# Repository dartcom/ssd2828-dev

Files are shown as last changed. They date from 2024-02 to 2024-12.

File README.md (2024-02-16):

# SSD2828-DEV
A collection of boards to test the SSD2828 RGB to MIPI Converter with the LH154Q01 panel by AUO and the VS035ZSM by BOE. The boards are meant to be ordered as a single unit and then be separated using a box cutter ( the dust generated by cutting cutting FR4 is carcenogenic PLEASE be carefull! ).

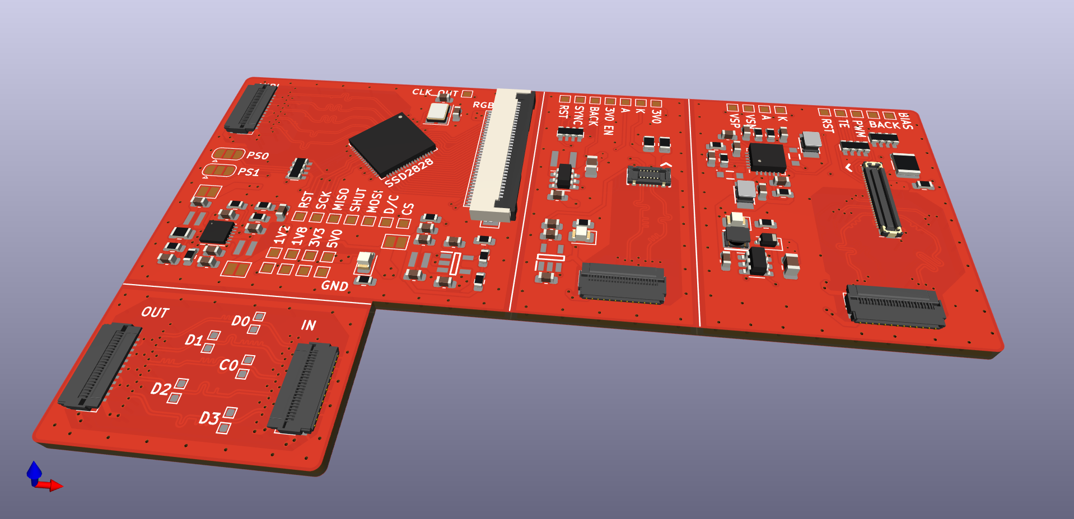
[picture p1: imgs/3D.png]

<br></br>

# The pcb
The pcb is designed using the JLC04161H-7628 stackup by JLCPCB.  The MIPI DSI protool requires controlled impedance traces to function properly (100Ω differental, 50Ω single ended), depending on the provided pcb stackup different trace widths and spacings need to be selected. Additionally the signals must be kept away from noise sources such as inductors and other signals. When switching layers with MIPI signals, GND vias need to be placed near the signal vias.

# LH154Q01 panel
The LH154Q01 panel has been tested and is working correctly.

The panel does not support packed pixel stream packets, the only way to send pixel data to the display, is through DCS commands. in this demo, a STM32f401 is sending the the write_memory_continue(0x3C) DCS command containing pixel data, through SPI to the SSD2828. 


<br></br>

# VS035ZSM panel
The VS035ZSM panel has been tested and is working correctly.

The panel gets initialized on MIPI LP mode and the video is transmitted MIPI HS mode @912Mbps per lane. The ssd2828 is generating the test video signal called BIST. The panel has 8-bit color depth, reaning each pixel requires 24bits. The resolution of the panel is 1400x1600, including the porch values the total resoution is 1470 x 167. To operate at 60fps, 1470 x 1670 x 24 x 60 = 3.53Gbps are required resulting at 883Mbps per lane. The panel also suppors VESA DSC making 90fps operation possible. Unfortunately the SSD2828 does not include a DSC encoder. 

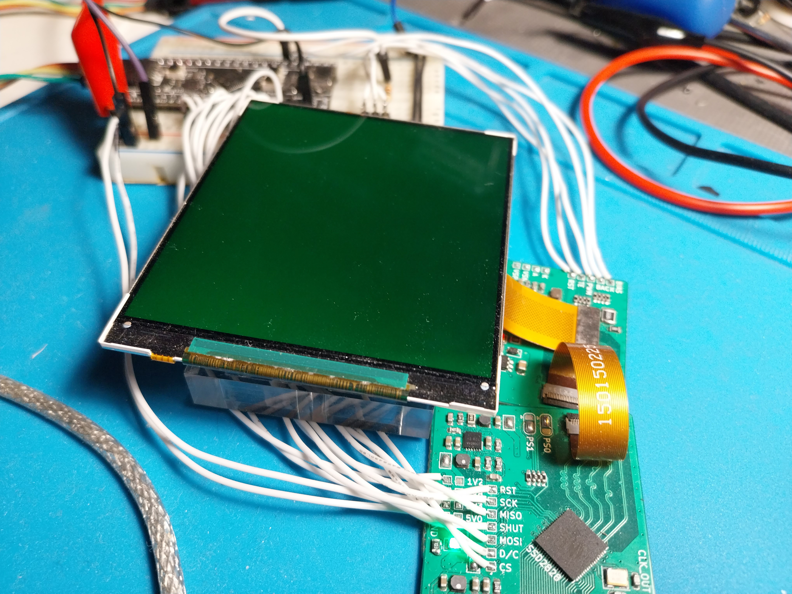
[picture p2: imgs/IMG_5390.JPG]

<br></br>

# Resources
### PCB
- [jlcpcb capabilities](https://jlcpcb.com/capabilities/pcb-capabilities).
- [jlcpcb impedance calculator](https://jlcpcb.com/pcb-impedance-calculator).
- [Jacinto 7 High-Speed Interface Layout Guidelines](https://www.ti.com/lit/an/spracp4/spracp4.pdf?ts=1708080453311&ref_url=https%253A%252F%252Fwww.google.com%252F).
- [MIPI DSI guidelines]( https://electronics.stackexchange.com/questions/610671/mipi-dsi-differential-pair-layout-guidance).
- [High-Speed PCB Design Tips - Phil's Lab](https://www.youtube.com/watch?v=VRJI0X-6yTg).
- [Differential Pairs - PCB Design Basics - Phil's Lab](https://www.youtube.com/watch?v=xwrdvhm4vgw).

### SSD2828
- [SSD2828 RGB转MIPI转换板制作（1)](https://blog.csdn.net/weixin_37214729/article/details/123339267).
- [SSD2828 RGB转MIPI转换板制作（2)](https://blog.csdn.net/weixin_37214729/article/details/127710648).
- [SSD2828调试记录](https://blog.csdn.net/luoqindong/article/details/39349333).
- [project-display](https://github.com/jlywxy/project-display).
- [Index of /lcd/ssd2828/](http://www.internetsomething.com/lcd/ssd2828/).

### LH154Q01
- [Driving IPOD Nano 6 MIPI LCD Using FPGA](https://www.circuitvalley.com/2020/01spi-mipi-bridge-fpga-verilog-hdl-ipod-nano-nano-lcd-iphone-mipi-lcd.html).
- [SSD2805 w/ LH154Q01](https://github.com/techtoys/SSD2805/blob/master/Microchip/Graphics/Drivers/SSD2805.c).
### VS035ZSM
- [Project North Star](https://github.com/leapmotion/ProjectNorthStar).

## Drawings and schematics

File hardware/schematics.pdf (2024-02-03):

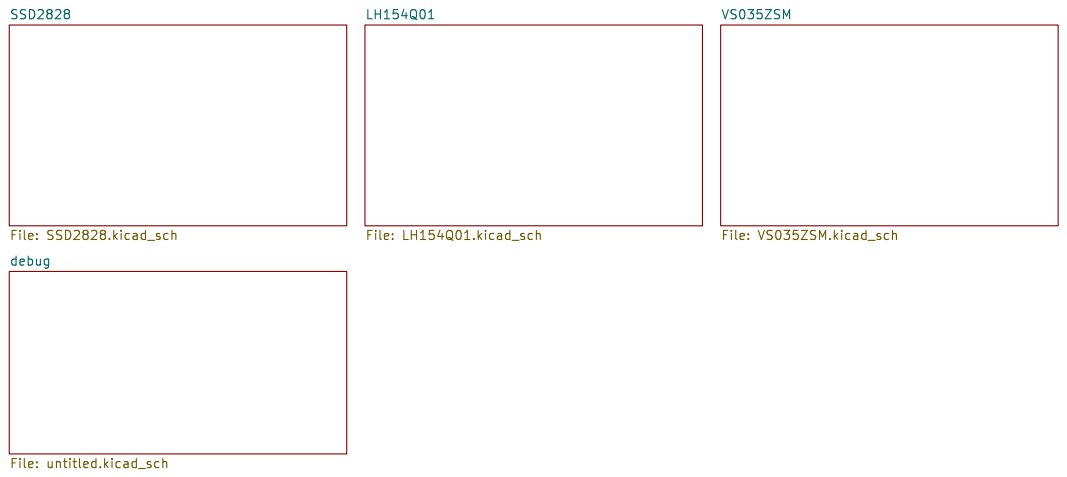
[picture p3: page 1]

debug File: untitled.kicad_sch SSD2828 File: SSD2828.kicad_sch

Id: 1/5 Title: File: ssd2828_board.kicad_sch Sheet: /

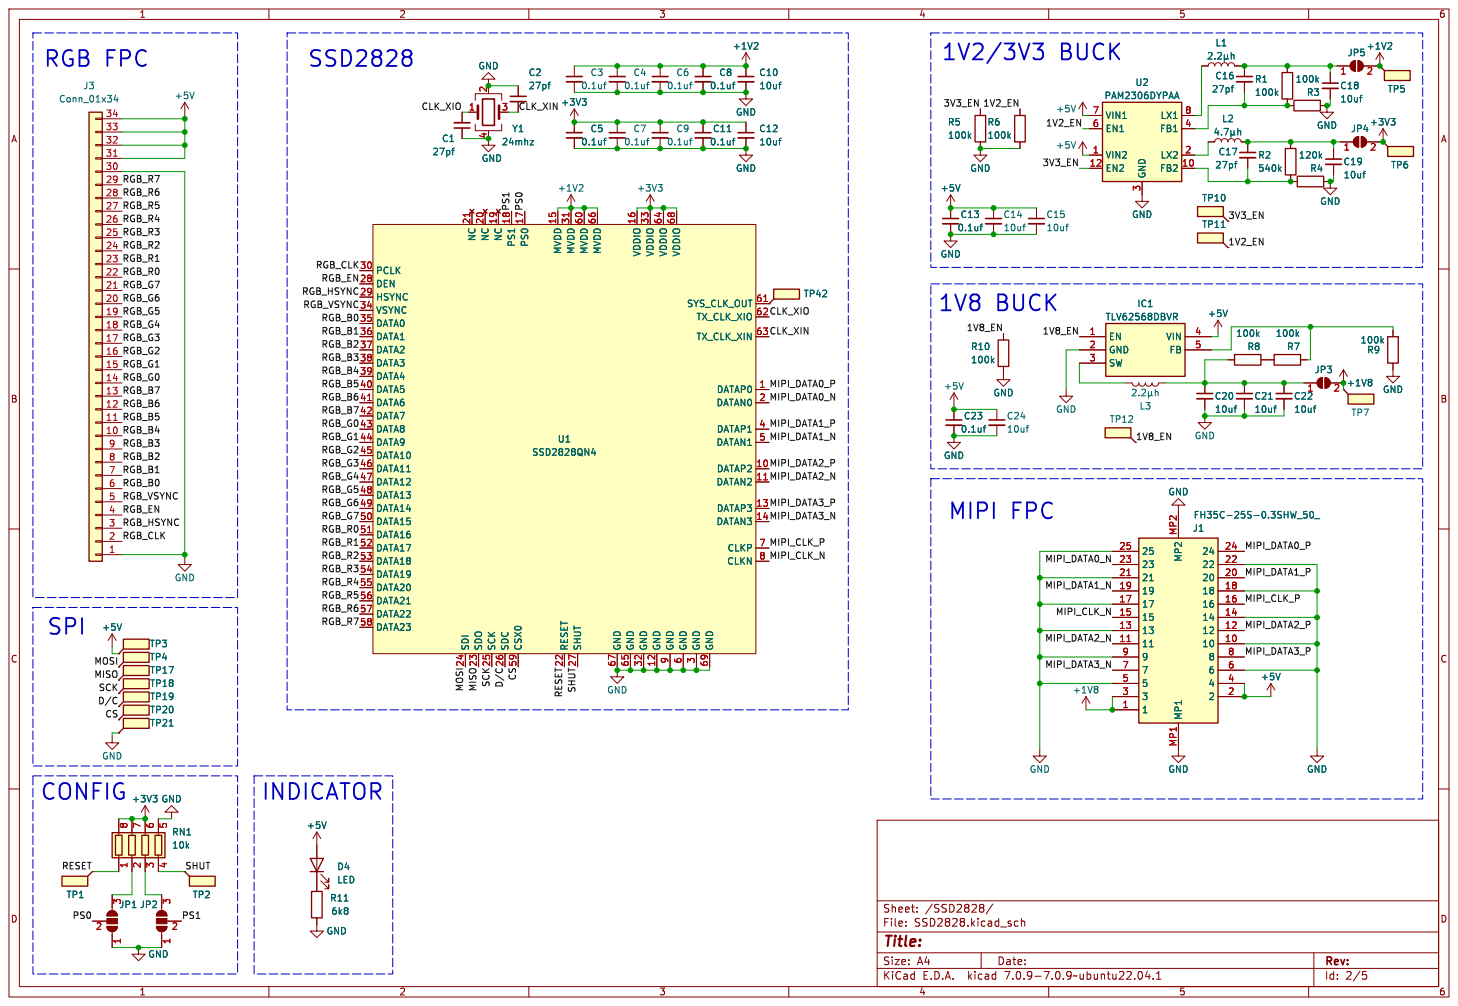
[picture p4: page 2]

3 PCLK 30 MVDD 31 GND 32 VDDIO 33 VSYNC 34 DATA0 35 DATA1 36 DATA2 37 DATA3 38 DATA4 39 DATAP1 4 DATA5 40 DATA6 41 DATA7 42 DATA8 43 DATA9 44 DATA10 45 DATA11 46 DATA12 47 DATA13 48 DATA14 49 DATAN1 5 DATA15 50 DATA16 51 DATA17 52 DATA18 53 DATA19 54 DATA20 55 DATA21 56 DATA22 57 DATA23 58 CSX0 59 GND

6 MVDD 60 SYS_CLK_OUT 61 TX_CLK_XIO 62 TX_CLK_XIN 63 VDDIO 64 GND 65 MVDD 66 GND 67 VDDIO 68 GND 69 CLKP 7 CLKN 8 GND

Id: 2/5 Title: File: SSD2828.kicad_sch Sheet: /SSD2828/

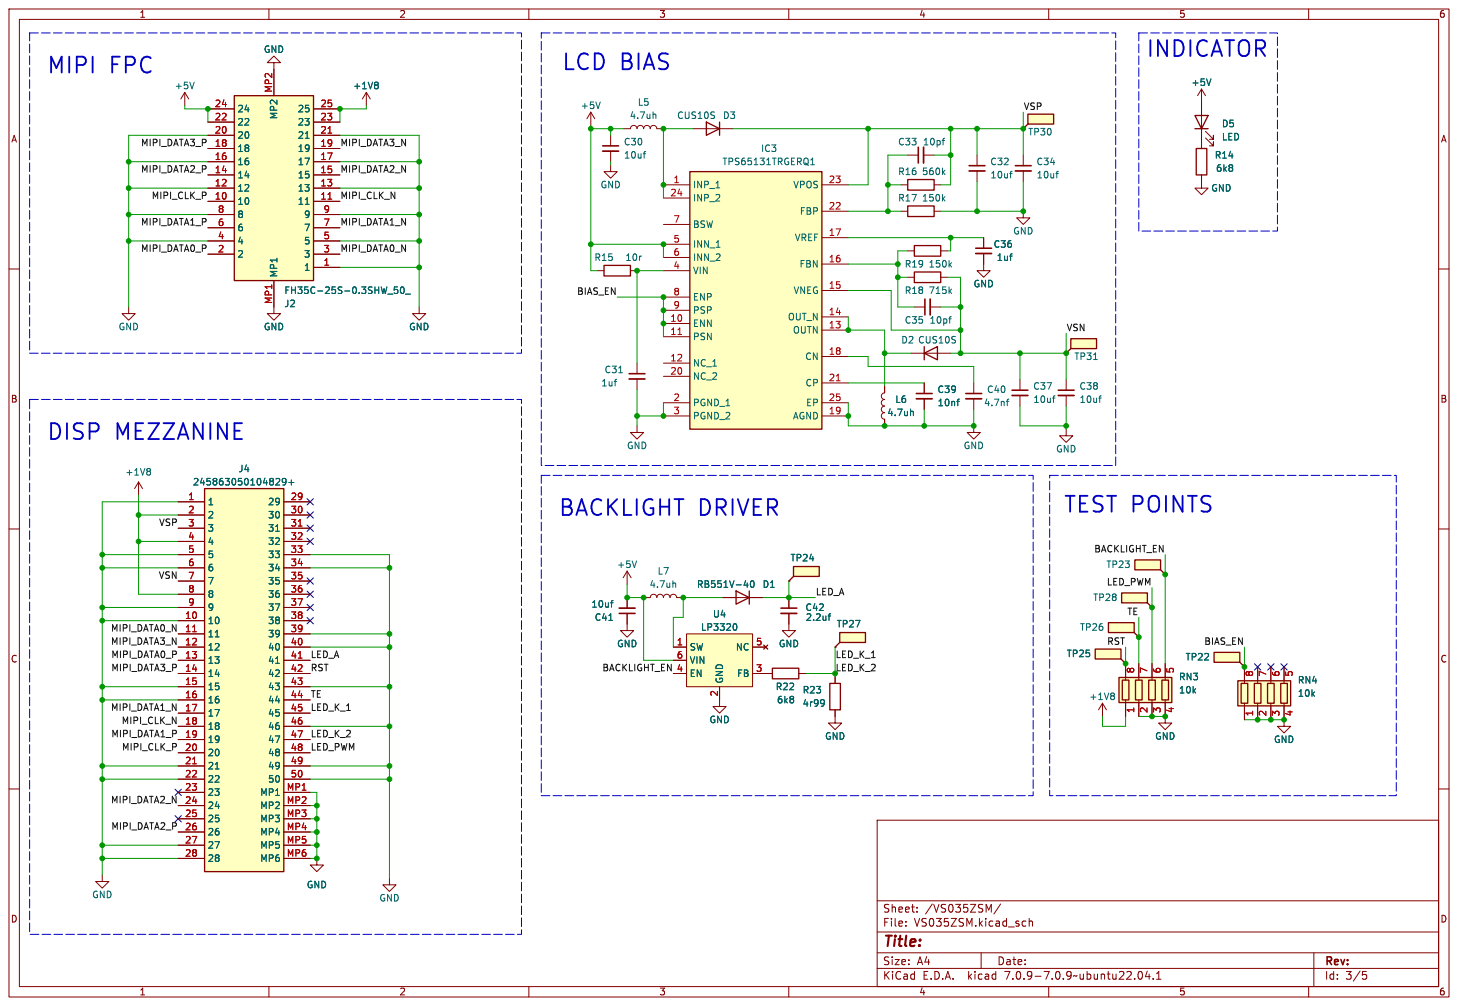
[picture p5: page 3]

2 FB 3 EN 4 NC 5 VIN 6 U4
2.2uf GND

2 FB 3 EN 4 NC 5 VIN 6 TP27 GND

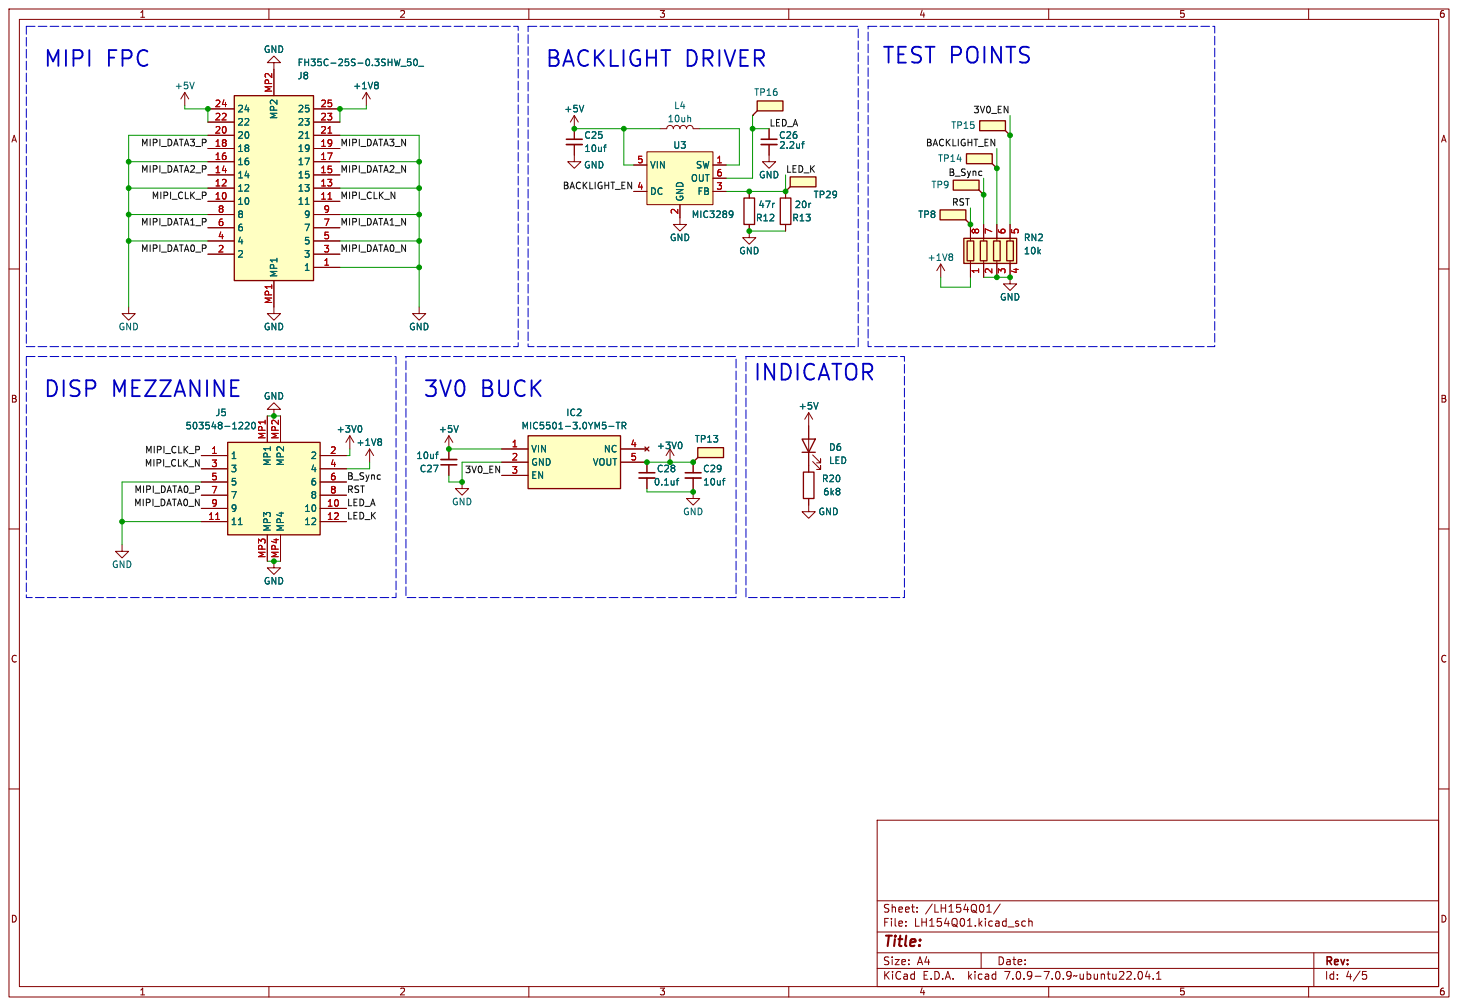
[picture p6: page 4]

2 FB 3 DC 4 VIN 5 OUT 6 U3 MIC3289 GND GND GND GND

2 FB 3 DC 4 VIN 5 OUT 6 GND

Id: 4/5 Title: File: LH154Q01.kicad_sch Sheet: /LH154Q01/

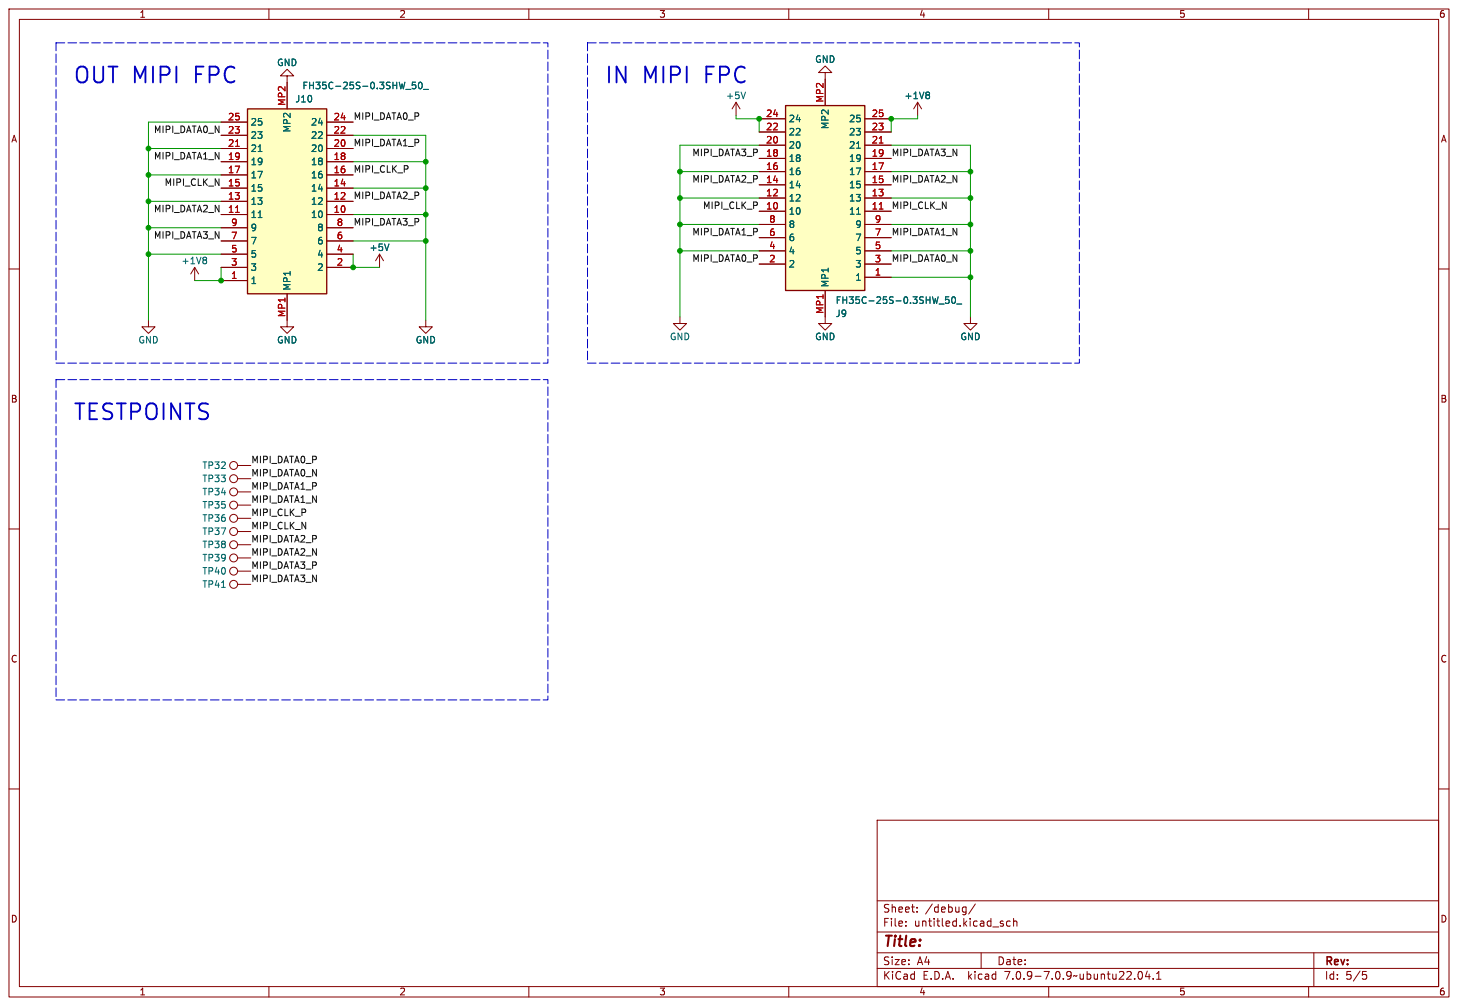
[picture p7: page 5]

Id: 5/5 Title: File: untitled.kicad_sch Sheet: /debug/

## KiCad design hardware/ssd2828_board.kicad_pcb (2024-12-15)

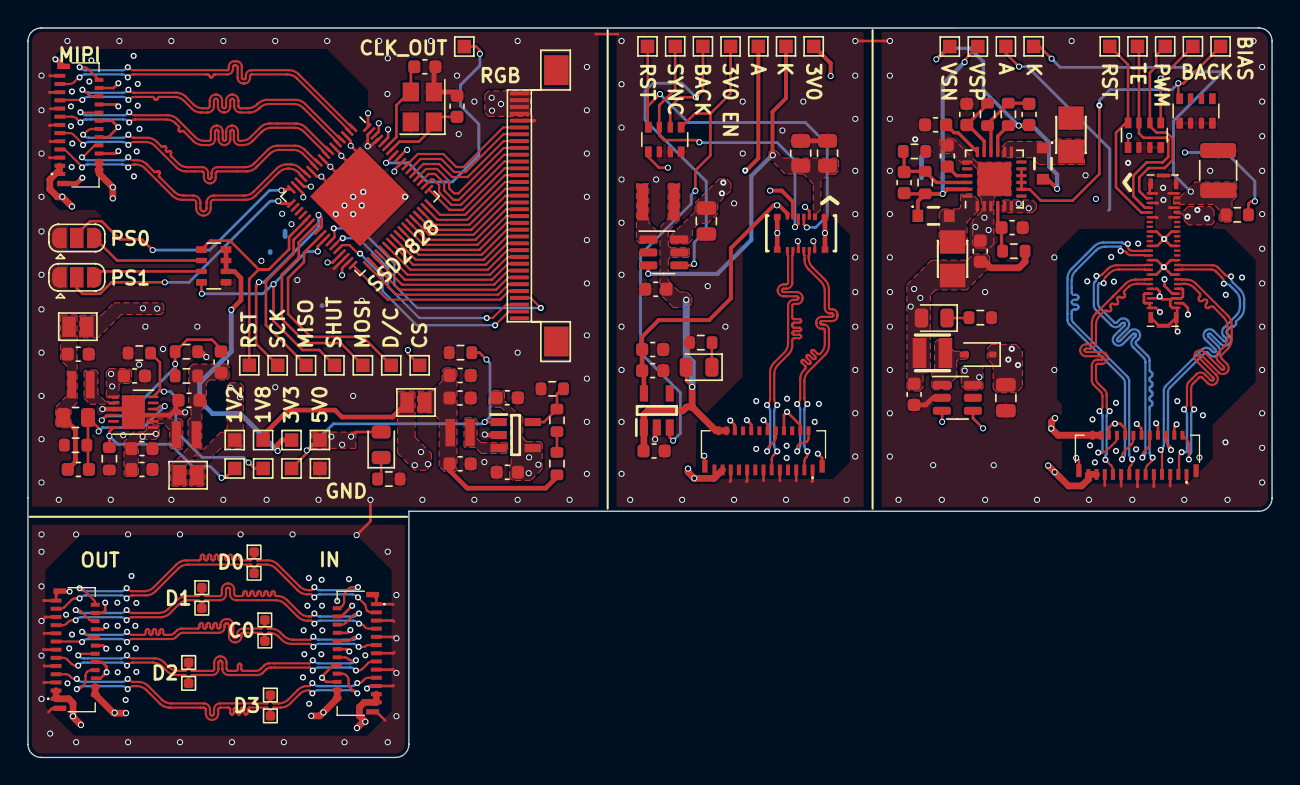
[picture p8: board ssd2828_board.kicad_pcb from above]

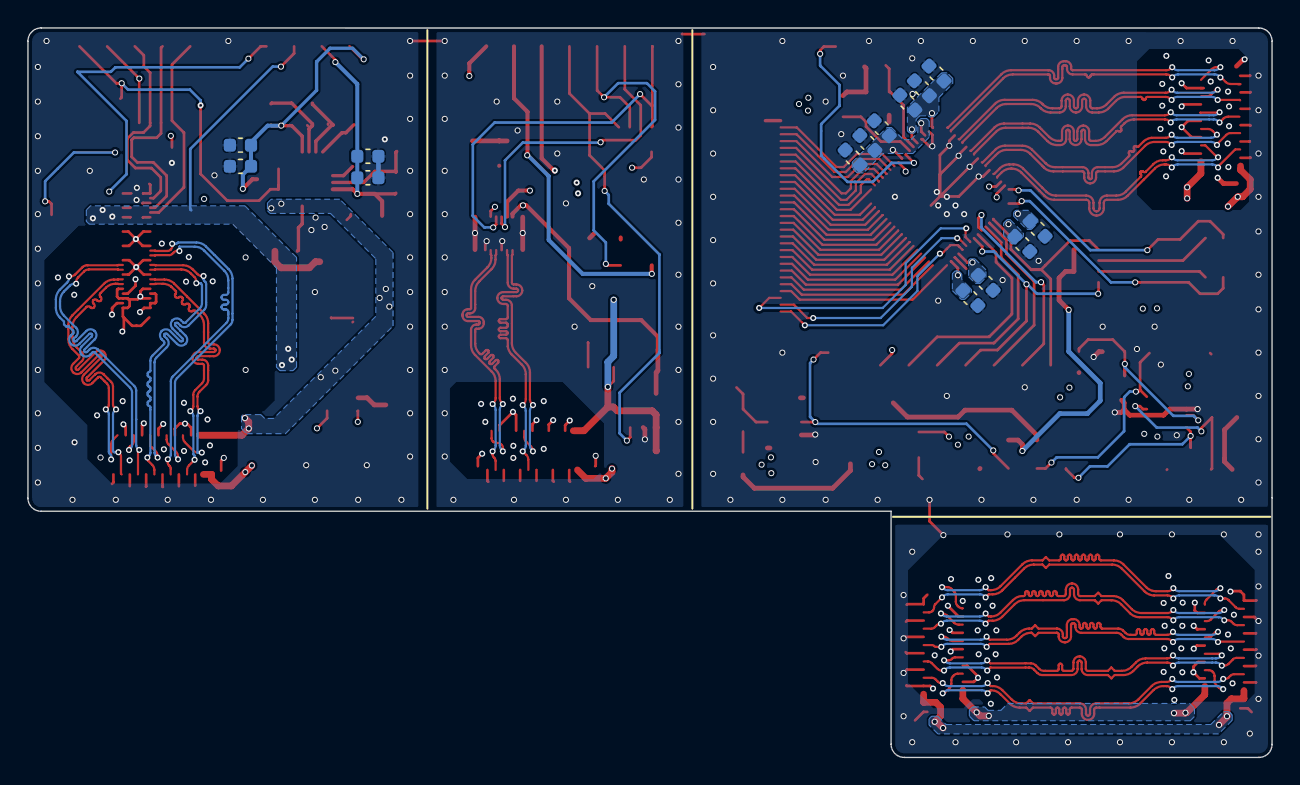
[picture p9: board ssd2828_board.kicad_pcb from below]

Board: 4 copper layers, 91.3 x 53.5 mm, 144 parts (14 on the bottom side), 124 nets.

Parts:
C1, C2, C16, C17: 27pf; C_0603_1608Metric
C3, C4, C5, C6, C7, C8, C9, C11, C13, C23, C28: 0.1uf; C_0603_1608Metric
C10, C12, C14, C15, C18, C19, C20, C21, C22, C24, C25, C27, C29, C30, C32, C34, C37, C38, C41: 10uf; C_0603_1608Metric
C26, C42: 2.2uf; C_0805_2012Metric
C31, C36: 1uf; C_0603_1608Metric
C33, C35: 10pf; C_0603_1608Metric
C39: 10nf; C_0603_1608Metric
C40: 4.7nf; C_0603_1608Metric
D1: RB551V-40; D_SOD-323
D2, D3: CUS10S; CUS10S40H3F
D4, D5, D6: LED; LED_0805_2012Metric
IC1: TLV62568DBVR; SOT95P280X145-5N
IC2: MIC5501-3.0YM5-TR; SOT95P280X145-5N
IC3: TPS65131TRGERQ1; VQFN-24-1EP_4x4mm_P0.5mm_EP2.45x2.45mm
J1, J2, J8, J9, J10: FH35C-25S-0.3SHW_50_; FH35C25S03SHW50
J3: Conn_01x34; FPC_34
J4: 245863050104829+; 245863050104829
J5: 503548-1220; 5035481220
JP1, JP2: SolderJumper-3_P1.3mm_Open_RoundedPad1.0x1.5mm
JP3, JP4, JP5: SolderJumper_2_Open; SolderJumper-2_P1.3mm_Open_Pad1.0x1.5mm
L1, L3: 2.2μh; NRH2410T2R2MN
L2: 4.7μh; NRS2012T4R7MGJ
L4: 10uh; ASPI0312FS100MT2
L5, L6: 4.7uh; IND-SMD_L2.5-W2.0_WPN252012H
L7: 4.7uh; IND-SMD_L2.5-W2.0_FHD252012S-6R8MT
R1, R3, R5, R6, R7, R8, R9, R10: 100k; R_0603_1608Metric
R2: 540k; R_0805_2012Metric
R4: 120k; R_0603_1608Metric
R11, R14, R20, R22: 6k8; R_0603_1608Metric
R12: 47r; R_0805_2012Metric
R13: 20r; R_0805_2012Metric
R15: 10r; R_0603_1608Metric
R16: 560k; R_0603_1608Metric
R17, R19: 150k; R_0603_1608Metric
R18: 715k; R_0603_1608Metric
R23: 4r99; R_1210_3225Metric
RN1, RN2, RN3, RN4: 10k; R_Array_Convex_4x0603
TP1, TP2, TP3, TP4, TP5, TP6, TP7, TP8, TP9, TP10, TP11, TP12, TP13, TP14, TP15, TP16, TP17, TP18, TP19, TP20, TP21, TP22, TP23, TP24, TP25, TP26, TP27, TP28, TP29, TP30, TP31, TP42: TestPoint_Pad_1.0x1.0mm
TP32, TP33, TP34, TP35, TP36, TP37, TP38, TP39, TP40, TP41: myTestpoint
U1: SSD2828QN4; QFN-68-1EP_8x8mm_P0.4mm_EP5.2x5.2mm
U2: PAM2306DYPAA; WDFN-12-1EP_3x3mm_P0.45mm_EP1.7x2.5mm
U3: MIC3289; SOT-23-6
U4: LP3320; SOT-23-6
Y1: 24mhz; Crystal_SMD_3225-4Pin_3.2x2.5mm

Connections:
+1V2: C3.1, C4.1, C6.1, C8.1, C10.1, JP5.2 (B), TP5.1, U1.15 (MVDD), U1.31 (MVDD), U1.60 (MVDD), U1.66 (MVDD)
+1V8: J1.1, J1.3, J2.23, J2.25, J4.2, J4.4, J4.8, J5.4, J8.23, J8.25, J9.23, J9.25, J10.1, J10.3, JP3.2 (B), RN2.1 (R1.1), RN3.1 (R1.1), TP7.1
+3V0: C28.1, C29.1, IC2.5 (VOUT), J5.2, TP13.1
+3V3: C5.1, C7.1, C9.1, C11.1, C12.1, JP4.2 (B), RN1.6 (R3.2), RN1.7 (R2.2), RN1.8 (R1.2), TP6.1, U1.16 (VDDIO), U1.33 (VDDIO), U1.64 (VDDIO), U1.68 (VDDIO)
+5V: C13.1, C14.1, C15.1, C23.1, C24.1, C25.1, C27.2, C30.1, C41.2, D4.2 (A), D5.2 (A), D6.2 (A), IC1.4 (VIN), IC2.1 (VIN), IC3.5 (INN_1), IC3.6 (INN_2), J1.2, J1.4, J2.22, J2.24, J3.31, J3.32, J3.33, J3.34, J8.22, J8.24, J9.22, J9.24, J10.2, J10.4, L4.1, L5.1, L7.1, R15.2, TP3.1, U2.1 (VIN2), U2.7 (VIN1), U3.5 (VIN), U4.6 (VIN)
/LH154Q01/3V0_EN: IC2.3 (EN), RN2.5 (R4.2), TP15.1
/LH154Q01/BACKLIGHT_EN: RN2.6 (R3.2), TP14.1, U3.4 (DC)
/LH154Q01/B_Sync: J5.6, RN2.7 (R2.2), TP9.1
/LH154Q01/LED_A: C26.1, J5.10, TP16.1, U3.6 (OUT)
/LH154Q01/LED_K: J5.12, R12.2, R13.2, TP29.1, U3.3 (FB)
/LH154Q01/MIPI_CLK_N: J5.3, J8.11
/LH154Q01/MIPI_CLK_P: J5.1, J8.10
/LH154Q01/MIPI_DATA0_N: J5.9, J8.3
/LH154Q01/MIPI_DATA0_P: J5.7, J8.2
/LH154Q01/RST: J5.8, RN2.8 (R1.2), TP8.1
/SSD2828/1V2_EN: R6.1, TP11.1, U2.6 (EN1)
/SSD2828/1V8_EN: IC1.1 (EN), R10.1, TP12.1
/SSD2828/3V3_EN: R5.1, TP10.1, U2.12 (EN2)
/SSD2828/CLK_XIN: C2.2, U1.63 (TX_CLK_XIN), Y1.3
/SSD2828/CLK_XIO: C1.2, U1.62 (TX_CLK_XIO), Y1.1
/SSD2828/CS: TP20.1, U1.59 (CSX0)
/SSD2828/D/C: TP19.1, U1.26 (SDC)
/SSD2828/MIPI_CLK_N: J1.15, U1.8 (CLKN)
/SSD2828/MIPI_CLK_P: J1.16, U1.7 (CLKP)
/SSD2828/MIPI_DATA0_N: J1.23, U1.2 (DATAN0)
/SSD2828/MIPI_DATA0_P: J1.24, U1.1 (DATAP0)
/SSD2828/MIPI_DATA1_N: J1.19, U1.5 (DATAN1)
/SSD2828/MIPI_DATA1_P: J1.20, U1.4 (DATAP1)
/SSD2828/MIPI_DATA2_N: J1.11, U1.11 (DATAN2)
/SSD2828/MIPI_DATA2_P: J1.12, U1.10 (DATAP2)
/SSD2828/MIPI_DATA3_N: J1.7, U1.14 (DATAN3)
/SSD2828/MIPI_DATA3_P: J1.8, U1.13 (DATAP3)
/SSD2828/MISO: TP17.1, U1.23 (SDO)
/SSD2828/MOSI: TP4.1, U1.24 (SDI)
/SSD2828/PS0: JP1.2 (C), U1.17 (PS0)
/SSD2828/PS1: JP2.2 (C), U1.18 (PS1)
/SSD2828/RESET: RN1.1 (R1.1), TP1.1, U1.22 (RESET)
/SSD2828/RGB_B0: J3.6, U1.35 (DATA0)
/SSD2828/RGB_B1: J3.7, U1.36 (DATA1)
/SSD2828/RGB_B2: J3.8, U1.37 (DATA2)
/SSD2828/RGB_B3: J3.9, U1.38 (DATA3)
/SSD2828/RGB_B4: J3.10, U1.39 (DATA4)
/SSD2828/RGB_B5: J3.11, U1.40 (DATA5)
/SSD2828/RGB_B6: J3.12, U1.41 (DATA6)
/SSD2828/RGB_B7: J3.13, U1.42 (DATA7)
/SSD2828/RGB_CLK: J3.2, U1.30 (PCLK)
/SSD2828/RGB_EN: J3.4, U1.28 (DEN)
/SSD2828/RGB_G0: J3.14, U1.43 (DATA8)
/SSD2828/RGB_G1: J3.15, U1.44 (DATA9)
/SSD2828/RGB_G2: J3.16, U1.45 (DATA10)
/SSD2828/RGB_G3: J3.17, U1.46 (DATA11)
/SSD2828/RGB_G4: J3.18, U1.47 (DATA12)
/SSD2828/RGB_G5: J3.19, U1.48 (DATA13)
/SSD2828/RGB_G6: J3.20, U1.49 (DATA14)
/SSD2828/RGB_G7: J3.21, U1.50 (DATA15)
/SSD2828/RGB_HSYNC: J3.3, U1.29 (HSYNC)
/SSD2828/RGB_R0: J3.22, U1.51 (DATA16)
/SSD2828/RGB_R1: J3.23, U1.52 (DATA17)
/SSD2828/RGB_R2: J3.24, U1.53 (DATA18)
/SSD2828/RGB_R3: J3.25, U1.54 (DATA19)
/SSD2828/RGB_R4: J3.26, U1.55 (DATA20)
/SSD2828/RGB_R5: J3.27, U1.56 (DATA21)
/SSD2828/RGB_R6: J3.28, U1.57 (DATA22)
/SSD2828/RGB_R7: J3.29, U1.58 (DATA23)
/SSD2828/RGB_VSYNC: J3.5, U1.34 (VSYNC)
/SSD2828/SCK: TP18.1, U1.25 (SCK)
/SSD2828/SHUT: RN1.4 (R4.1), TP2.1, U1.27 (SHUT)
/VS035ZSM/BACKLIGHT_EN: RN3.5 (R4.2), TP23.1, U4.4 (EN)
/VS035ZSM/BIAS_EN: IC3.8 (ENP), IC3.9 (PSP), IC3.10 (ENN), IC3.11 (PSN), RN4.8 (R1.2), TP22.1
/VS035ZSM/LED_A: C42.1, D1.1 (K), J4.41, TP24.1
/VS035ZSM/LED_K_1: J4.45, J4.47, R22.2, R23.1, TP27.1
/VS035ZSM/LED_PWM: J4.48, RN3.6 (R3.2), TP28.1
/VS035ZSM/MIPI_CLK_N: J2.11, J4.18
/VS035ZSM/MIPI_CLK_P: J2.10, J4.20
/VS035ZSM/MIPI_DATA0_N: J2.3, J4.11
/VS035ZSM/MIPI_DATA0_P: J2.2, J4.13
/VS035ZSM/MIPI_DATA1_N: J2.7, J4.17
/VS035ZSM/MIPI_DATA1_P: J2.6, J4.19
/VS035ZSM/MIPI_DATA2_N: J2.15, J4.24
/VS035ZSM/MIPI_DATA2_P: J2.14, J4.26
/VS035ZSM/MIPI_DATA3_N: J2.19, J4.12
/VS035ZSM/MIPI_DATA3_P: J2.18, J4.14
/VS035ZSM/RST: J4.42, RN3.8 (R1.2), TP25.1
/VS035ZSM/TE: J4.44, RN3.7 (R2.2), TP26.1
/VS035ZSM/VSN: C35.2, C37.1, C38.1, D2.2 (A), IC3.15 (VNEG), J4.7, R18.2, TP31.1
/VS035ZSM/VSP: C32.1, C33.2, C34.1, D3.1 (K), IC3.23 (VPOS), J4.3, R16.2, TP30.1
/debug/MIPI_CLK_N: J9.11, J10.15, TP37.1
/debug/MIPI_CLK_P: J9.10, J10.16, TP36.1
/debug/MIPI_DATA0_N: J9.3, J10.23, TP33.1
/debug/MIPI_DATA0_P: J9.2, J10.24, TP32.1
/debug/MIPI_DATA1_N: J9.7, J10.19, TP35.1
/debug/MIPI_DATA1_P: J9.6, J10.20, TP34.1
/debug/MIPI_DATA2_N: J9.15, J10.11, TP39.1
/debug/MIPI_DATA2_P: J9.14, J10.12, TP38.1
/debug/MIPI_DATA3_N: J9.19, J10.7, TP41.1
/debug/MIPI_DATA3_P: J9.18, J10.8, TP40.1
GND: C1.1, C2.1, C3.2, C4.2, C5.2, C6.2, C7.2, C8.2, C9.2, C10.2, C11.2, C12.2, C13.2, C14.2, C15.2, C18.2, C19.2, C20.2, C21.2, C22.2, C23.2, C24.2, C25.2, C26.2, C27.1, C28.2, C29.2, C30.2, C31.2, C32.2, C34.2, C36.2, C37.2, C38.2, C39.2, C40.2, C41.1, C42.2, IC1.2 (GND), IC2.2 (GND), IC3.2 (PGND_1), IC3.3 (PGND_2), IC3.19 (AGND), IC3.25 (EP), J1.5, J1.6, J1.9, J1.10, J1.13, J1.14, J1.17, J1.18, J1.21, J1.22, J1.25, J1.MP1, J1.MP2, J2.1, J2.4, J2.5, J2.8, J2.9, J2.12, J2.13, J2.16, J2.17, J2.20, J2.21, J2.MP1, J2.MP2, J3.1, J3.30, J4.1, J4.5, J4.6, J4.9, J4.10, J4.15, J4.16, J4.21, J4.22, J4.27, J4.28, J4.33, J4.34, J4.39, J4.40, J4.43, J4.46, J4.49, J4.50, J4.MP1, J4.MP2, J4.MP3, J4.MP4, J4.MP5, J4.MP6, J5.5, J5.11, J5.MP1, J5.MP2, J5.MP3, J5.MP4, J8.1, J8.4, J8.5, J8.8, J8.9, J8.12, J8.13, J8.16, J8.17, J8.20, J8.21, J8.MP1, J8.MP2, J9.1, J9.4, J9.5, J9.8, J9.9, J9.12, J9.13, J9.16, J9.17, J9.20, J9.21, J9.MP1, J9.MP2, J10.5, J10.6, J10.9, J10.10, J10.13, J10.14, J10.17, J10.18, J10.21, J10.22, J10.25, J10.MP1, J10.MP2, JP1.1 (A), JP2.1 (A), L6.1, R3.2, R4.2, R5.2, R6.2, R9.2, R10.2, R11.1, R12.1, R13.1, R14.1, R17.2, R20.1, R23.2, RN1.5 (R4.2), RN2.2 (R2.1), RN2.3 (R3.1), RN2.4 (R4.1), RN3.2 (R2.1), RN3.3 (R3.1), RN3.4 (R4.1), RN4.1 (R1.1), RN4.2 (R2.1), RN4.3 (R3.1), RN4.4 (R4.1), TP21.1, U1.3 (GND), U1.6 (GND), U1.9 (GND), U1.12 (GND), U1.32 (GND), U1.65 (GND), U1.67 (GND), U1.69 (GND), U2.3 (GND), U2.9 (GND), U2.13 (GND), U3.2 (GND), U4.2 (GND), Y1.2, Y1.4
unnamed: D1.2 (A), L7.2, U4.1 (SW)
unnamed: D2.1 (K), IC3.13 (OUTN), IC3.14 (OUT_N), L6.2
unnamed: D3.2 (A), IC3.1 (INP_1), IC3.24 (INP_2), L5.2
unnamed: D4.1 (K), R11.2
unnamed: D5.1 (K), R14.2
unnamed: D6.1 (K), R20.2
unnamed: IC1.5 (FB), R7.2, R9.1
unnamed: IC1.3 (SW), L3.1
unnamed: C40.1, IC3.18 (CN)
unnamed: C39.1, IC3.21 (CP)
unnamed: C35.1, IC3.16 (FBN), R18.1, R19.1
unnamed: C33.1, IC3.22 (FBP), R16.1, R17.1
unnamed: C31.1, IC3.4 (VIN), R15.1
unnamed: C36.1, IC3.17 (VREF), R19.2
unnamed: JP1.3 (B), RN1.2 (R2.1)
unnamed: JP2.3 (B), RN1.3 (R3.1)
unnamed: C20.1, C21.1, C22.1, JP3.1 (A), L3.2, R8.1
unnamed: C17.1, C19.1, JP4.1 (A), L2.2, R2.1
unnamed: C16.1, C18.1, JP5.1 (A), L1.2, R1.1
unnamed: R7.1, R8.2
unnamed: TP42.1, U1.61 (SYS_CLK_OUT)
unnamed: C16.2, R1.2, R3.1, U2.4 (FB1)
unnamed: C17.2, R2.2, R4.1, U2.10 (FB2)
unnamed: L1.1, U2.8 (LX1)
unnamed: L2.1, U2.2 (LX2)
unnamed: L4.2, U3.1 (SW)
unnamed: R22.1, U4.3 (FB)

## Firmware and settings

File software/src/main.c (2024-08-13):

#include <stdint.h>
#include <stddef.h>
#include <string.h>
#include <stdlib.h>
#include <stdio.h>
#include "../system/stm32f4xx.h"

#include "../libs/delay.h"
#include "../libs/spi.h"

#include "ssd2828.h"
#include "LH154Q01.h"
#include "VS035ZSM.h"
#include "clk.h"



void gpio_init(){
    //enable GPIOC and GPIOA GPIOB GPIOC
    RCC->AHB1ENR |= RCC_AHB1ENR_GPIOCEN | RCC_AHB1ENR_GPIOAEN | RCC_AHB1ENR_GPIOBEN;
    //set C13 to output
    GPIOC->MODER |= (0x1<<GPIO_MODER_MODER13_Pos);
    //C13 to push pull
    GPIOC->OTYPER &= ~GPIO_OTYPER_OT13;
    //set C13 speed to low
    GPIOC->OSPEEDR &= ~GPIO_OSPEEDER_OSPEEDR13;
    //set C13 to LOW
    GPIOC->ODR |= GPIO_ODR_OD13;

}


void fill_line(uint8_t r, uint8_t g, uint8_t b){
    uint32_t i;
    ssd2828_SPI_write_reg(PSCR1_REG, ((240*3)+1)&0x0FFF);
    ssd2828_SPI_write_cmd(PDR_REG);//0xBF
    ssd2828_SPI_write_data(0x3C);
    for(i = 0; i < 240; i++){
        ssd2828_SPI_write_data(r);
        ssd2828_SPI_write_data(g);
        ssd2828_SPI_write_data(b);
    }
}

void fill_screen(uint8_t r, uint8_t g, uint8_t b){
    uint32_t i;
    for(i = 0; i < 240; i++){
        fill_line(r,g,b);
    }
}

int main(){
    uint16_t i,j = 0;
    SystemClock_Config();
    gpio_init();
    delay_init();
    spi_init();
    delay_ms(550);
    
    
    
    ssd2828_init();
    //LH154Q01_init();
    //LH154Q01_SSD2828_write_cfg();
    //LH154Q01_start();
    //LH154Q01_backlight(1);
    VS035ZSM_init();
    VS035ZSM_init_BACKLIGHT();
    VS035ZSM_SSD2828_write_cfg();
    ssd2828_set_LP();
    VS035ZSM_start();
    
    VS035ZSM_backlight(1);
    ssd2828_set_HS();
    ssd2828_BIST_ON();
    //VS035ZSM_set_partial(); 
    ssd2828_VID_ON();
    GPIOC->ODR ^= GPIO_ODR_OD13;
   
    while(1){
        i = ssd2828_get_id();
        if(i == 0x2828){
            GPIOC->ODR ^= GPIO_ODR_OD13;
        }
        

        delay_ms(100);
       
    }
    return 0;
}

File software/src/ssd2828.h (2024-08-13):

#ifndef SSD2828_H
#define SSD2828_H

#include <stdint.h>
#include <stdio.h>
#include "../system/stm32f4xx.h"

#include "../libs/delay.h"
#include "../libs/spi.h"

#include "DCS.h"

#define SSD2828_C_PORT  GPIOA
#define SSD2828_RST     3U
#define SSD2828_DC      1U
#define SSD2828_SHUT    2U

#define SSD2828_V_PORT  GPIOB
#define SSD2828_1V2     2U
#define SSD2828_3V3     0U



struct SSD2828_LCD_PARAMS{
    uint16_t VSPW;
    uint16_t HSPW;
    uint16_t VBPD;
    uint16_t HBPD;
    uint16_t VFPD;
    uint16_t HFPD;
    uint16_t XSIZE;
    uint16_t YSIZE;
    uint16_t lanes;
};


#define DIR_REG     0xB0

#define VICR1_REG   0xB1
    #define VICR1_VSA_POS                   8U
    #define VICR1_VSA_MSK                   0xFF00
    #define VICR1_HSA_POS                   0U
    #define VICR1_HSA_MSK                   0x00FF

#define VICR2_REG   0xB2
    #define VICR2_VBP_POS                   8U
    #define VICR2_VBP_MSK                   0xFF00
    #define VICR2_HBP_POS                   0U
    #define VICR2_HBP_MSK                   0x00FF

#define VICR3_REG   0xB3
    #define VICR3_VFP_POS                   8U
    #define VICR3_VFP_MSK                   0xFF00
    #define VICR3_HFP_POS                   0U
    #define VICR3_HFP_MSK                   0x00FF

#define VICR4_REG   0xB4
    #define VICR4_HACT_POS                  0U
    #define VICR4_HACT_MSK                  0xFFFF

#define VICR5_REG   0xB5
    #define VICR5_VACT_POS                  0U
    #define VICR5_VACT_MSK                  0xFFFF

#define VICR6_REG   0xB6
    #define VICR6_VS_P_POS                  15U
    #define VICR6_VS_P_MSK                  0x8000
    #define VICR6_HS_P_POS                  14U
    #define VICR6_HS_P_MSK                  0x4000
    #define VICR6_PCLK_P_POS                13U
    #define VICR6_PCLK_P_MSK                0x2000
    #define VICR6_CBM_POS                   8U
    #define VICR6_CBM_MSK                   0x0100
    #define VICR6_NVB_POS                   7U
    #define VICR6_NVB_MSK                   0x0080
    #define VICR6_NVD_POS                   6U
    #define VICR6_NVD_MSK                   0x0040
    #define VICR6_BLLP_POS                  5U
    #define VICR6_BLLP_MSK                  0x0020
    #define VICR6_VCS_POS                   4U
    #define VICR6_VCS_MSK                   0x0010
    #define VICR6_VM_POS                    2U
    #define VICR6_VM_MSK                    0x000C
    #define VICR6_VPF_POS                   0U
    #define VICR6_VPF_MSK                   0x0003

#define CFGR_REG    0xB7
    #define CFGR_TXD_POS                    11U
    #define CFGR_TXD_MSK                    0x0800
    #define CFGR_LPE_POS                    10U
    #define CFGR_LPE_MSK                    0x0400
    #define CFGR_EOT_POS                    9U
    #define CFGR_EOT_MSK                    0x0200
    #define CFGR_ECD_POS                    8U
    #define CFGR_ECD_MSK                    0x0100
    #define CFGR_REN_POS                    7U
    #define CFGR_REN_MSK                    0x0080
    #define CFGR_DCS_POS                    6U
    #define CFGR_DCS_MSK                    0x0040
    #define CFGR_CSS_POS                    5U
    #define CFGR_CSS_MSK                    0x0020
    #define CFGR_HCLK_POS                   4U
    #define CFGR_HCLK_MSK                   0x0010
    #define CFGR_VEN_POS                    3U
    #define CFGR_VEN_MSK                    0x0008
    #define CFGR_SLP_POS                    2U
    #define CFGR_SLP_MSK                    0x0004
    #define CFGR_CKE_POS                    1U
    #define CFGR_CKE_MSK                    0x0002
    #define CFGR_HS_POS                     0U
    #define CFGR_HS_MSK                     0x0001

#define VCR_REG     0xB8
    #define VCR_VCM_POS                     6U
    #define VCR_VCM_MSK                     0x00C0
    #define VCR_VCE_POS                     4U
    #define VCR_VCE_MSK                     0x0030
    #define VCR_VC2_POS                     2U
    #define VCR_VC2_MSK                     0x000C
    #define VCR_VC1_POS                     0U
    #define VCR_VC1_MSK                     0x0003

#define PCR_REG     0xB9
    #define PCR_SYSD_POS                    14U
    #define PCR_SYSD_MSK                    0xC000
    #define PCR_SYS_DIS_POS                 13U
    #define PCR_SYS_DIS_MSK                 0x2000
    #define PCR_PEN_POS                     0U
    #define PCR_PEN_MSK                     0x0001

#define PLCR_REG    0xBA
    #define PLCR_FR_POS                     14U
    #define PLCR_FR_MSK                     0xC000
    #define PLCR_MS_POS                     8U
    #define PLCR_MS_MSK                     0x1F00
    #define PLCR_NS_POS                     0U
    #define PLCR_NS_MSK                     0x00FF

#define CCR_REG     0xBB
    #define CCR_LPD_POS                     0U
    #define CCR_LPD_MSK                     0x003F

#define PSCR1_REG   0xBC
    #define PSCR1_TDC_POS                   0U
    #define PSCR1_TDC_MSK                   0xFFFF

#define PSCR2_REG   0xBD
    #define PSCR2_TDC_POS                   0U
    #define PSCR2_TDC_MSK                   0xFFFF

#define PSCR3_REG   0xBE
    #define PSCR3_PST_POS                   0U
    #define PSCR3_PST_MSK                   0x1FFF

#define PDR_REG     0xBF
    #define PDR_GPD_POS                     0U
    #define PDR_GPD_MSK                     0xFFFF

#define OCR_REG     0xC0
    #define OCR_RST_POS                     8U
    #define OCR_RST_MSK                     0x0100
    #define OCR_COP_POS                     0U
    #define OCR_COP_MSK                     0x0001

#define MRSR_REG    0xC1
    #define MRSR_MRS_POS                    0U
    #define MRSR_MRS_MSK                    0xFFFF

#define RDCR_REG    0xC2
    #define RDCR_RDC_POS                    0U
    #define RDCR_RDC_MSK                    0xFFFF

#define ARSR_REG    0xC3
    #define ARSR_AR_POS                     0U
    #define ARSR_AR_MSK                     0xFFFF

#define LCR_REG     0xC4
    #define LCR_IBC_POS                     5U
    #define LCR_IBC_MSK                     0x0020
    #define LCR_RT_POS                      4U
    #define LCR_RT_MSK                      0x0010
    #define LCR_RTB_POS                     3U
    #define LCR_RTB_MSK                     0x0008
    #define LCR_FBC_POS                     2U
    #define LCR_FBC_MSK                     0x0004
    #define LCR_FBT_POS                     1U
    #define LCR_FBT_MSK                     0x0002
    #define LCR_FBW_POS                     0U
    #define LCR_FBW_MSK                     0x0001
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

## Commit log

2023-07-12 fixed some intra-pair skew errors and filleted some lanes
    [ssd2828_board.kicad_pcb]
2023-07-12 added separations for each board on the copper fills
    [ssd2828_board.kicad_pcb]
2023-07-15 tweaked some MIPI traces on the SSD2828 board
    [ssd2828_board.kicad_pcb]
2023-07-16 added solder bridges on all the generated voltage rails on the SSD2828 board
    [LH154Q01.kicad_sch, SSD2828.kicad_sch, VS035ZSM.kicad_sch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]
2023-07-17 updated tps6513 footprint to vqfn24 + fixed some missing connections near it
    [VS035ZSM.kicad_sch, ssd2828_board.kicad_pcb]
2023-07-27 changed the order of pins on the rgb connector + removed a pin from the schematic symbol
    [SSD2828.kicad_sch, ssd2828_board.kicad_pcb]
2023-08-14 retouched copper fills + started reordering the power nets
    [SSD2828.kicad_sch, ssd2828_board.kicad_pcb]
2023-08-26 fixing drc errors + adding debug board for mipi
    [ssd2828_board-B_Cu.gbl, ssd2828_board-B_Mask.gbs, ssd2828_board-B_Paste.gbp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]
2023-09-14 routed 1v2 to ssd2828 + finished debug board
    [SSD2828.kicad_sch, ssd2828_board.kicad_pcb]
2023-09-25 finished with vias + fixed board outlines
    [ssd2828_board.kicad_pcb]
2023-09-27 making the project portableby moving external libaries to the project
    [SSD2828.kicad_sch, ssd2828_board.kicad_pcb]
2023-10-01 updated 3d models to the correct paths for kicad 7 + added HTML interactive BOM
    [ssd2828_board.kicad_pcb]
2023-10-15 added via stitching and updated the bias generator layout
    [LH154Q01.kicad_sch, VS035ZSM.kicad_sch, ssd2828_board.kicad_pcb]
2023-11-02 fixed details
    [SSD2828.kicad_sch, VS035ZSM.kicad_sch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]
2023-11-02 fixed some 3d models + redid power distribution on the BOE board
    [VS035ZSM.kicad_sch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]
2023-11-02 added fresh gerbers
2023-11-02 version 1.0
    [LH154Q01.kicad_sch, SSD2828.kicad_sch, VS035ZSM.kicad_sch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]
2023-11-16 added copper pour on back layer to adhere with jlcpcb guidelines
    [ssd2828_board-B_Cu.gbl, ssd2828_board-B_Mask.gbs, ssd2828_board-B_Paste.gbp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]
2023-11-30 fixed hirose FPC connector poinitng backwards on the 2 lcd boards+added stm32f401 boilerplate code
    [LH154Q01.kicad_sch, SSD2828.kicad_sch, VS035ZSM.kicad_sch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]
2023-11-30 length tuned mipi lines on ssd2828 board
    [ssd2828_board.kicad_pcb]
2023-12-01 added config for cortex debug + added blink for stm32
2024-02-03 updated readme + fixed pcb + cleaned up code
    [ssd2828_board.kicad_pcb, untitled.kicad_sch]
2024-02-04 started on the code for the BOE panel + fixed VSN VSP labels on PCB
    [ssd2828_board.kicad_pcb]
2024-12-15 fixed kicad performance issues with GND plane
    [ssd2828_board.kicad_pcb]
